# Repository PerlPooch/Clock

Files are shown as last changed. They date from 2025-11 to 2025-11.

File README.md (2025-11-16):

# Hardware

You can power Clock via the NodeMCU micro-USB port, but it is preferable to provide +5V power via the on-board connector or terminal J1. Driving the LEDs brighter than 50% when powered via the micro-USB connector may damage the NodeMCU.

A ring of 60 WS2812B LEDs are connected to J5 or J2 (but not both). Pin 1 is ground, Pin 2 is data, Pin 3 is +5. See [[RGB Clock Controller/Schematic.pdf][The Schematic]] for details. 

Dual connectors J3 are provided for an optional small OLED display. Select the header that matches the orientation of the display.

# Software 2.11

## Wifi Configuration

If there is no configuration present or Clock is powered-on with button (SW3) depressed, Clock enters WiFi configuration mode.

In this mode, Clock will create a WiFi access point with the SSID `Clock xx:xx:xx:xx:xx:xx`. Join this AP with the password `12345678` and you will be presented with menus through which you can select and join an Internet-connected AP.

Once configured, Clock will reboot.

## USB-Serial Access

Clock will provide a serial interface via USB at 115200/8/n/1.

## OpenWeather

If you have an OpenWeather key, Clock will obtain the weather by making requests to 

    GET http://api.openweathermap.org/data/2.5/weather

using the configured key. You must set `owAppKey`, `latitude`, and `longitude`.

## Start Up

Clock will test the display, connect to the configured WiFi AP, and retrieve the current date and time via NTP. 

## Configuration

You can reach Clock via HTTP at its address. If you don't know the address that was assigned, you can enter WiFi Configuration mode and view the assigned IP address. Alternatively, the assigned IP address is available via the Serial connection upon start up.

### Query Values and Status

Making a GET request to / will return a JSON payload of the current configuration. 

    http://<clockip>/

| Field | Meaning / Range |
| :--- | :--- |
| **"sleepRemaining"** | `<int>` – Remaining **sleep time** in seconds |
| **"timezone"** | `<int>` – **Timezone offset** from OpenWeather data |
| **"nextNTPUpdate"**  | `<int>` – Seconds until the next **NTP time update** |
| **"nextOWUpdate"** | `<int>` – Seconds until the next **OpenWeather update** |
| **"temperature"** | `<int>` – Current **temperature (°F)** |
| **"lastOWResponse"** | `<int>` – Last **HTTP response code** from OpenWeather |
| **"time"** | `<string>` – Current **time** |
| **"display"** | `<string>` – Display state (**Day**, **Night**, **Sleep**, or **Preparing**) |
| **"version"** | `<string>` – Clock **firmware version** |

### Set Values

Making a GET request with a query-string can configure the options. 

For example, to set the dim intensity and bright intensity for both daytime and nighttime modes:

    http://clockip/?dim=7&bright=20&dimNight=7&brightNight=20

| Option | Meaning / Range |
| :--- | :--- |
| **"dim"** | `0 .. 100` – Brightness of standard dots during **Day time** |
| **"bright"** | `0 .. 100` – Brightness of tick dots during **Day time** |
| **"dimNight"** | `0 .. 100` – Brightness of standard dots during **Night time** |
| **"brightNight"**  | `0 .. 100` – Brightness of tick dots during **Night time** |
| **"temp"** | `0 .. 100` – Brightness of temperature dot when **sleeping** |
| **"hue"** | `0 .. 100` – Universal **color shift** to apply |
| **"coldHue"** | `0 .. 100` – Color of temperature dot when **temperature < 60°** |
| **"warmHue"** | `0 .. 100` – Color of temperature dot when **temperature > 60°** |
| **"nightHour"** | `0 .. 23` – Hour to **start Night time** |
| **"dayHour"** | `0 .. 23` – Hour to **end Night time** |
| **"owAppKey"** | `<string>` – **OpenWeather API Key** |
| **"latitude"** | `<float>` – Location **Latitude** |
| **"longitude"** | `<float>` – Location **Longitude** |
| **"displaySleep"** | `<int>` – Sleep the display for this many **seconds** |
| **"reboot"** | `<>` – **Reboot** |

## OTA Firmware Update

    GET http://<clockip>/_ac/update

## WiFi Configuration Changes

    GET http://<clockip>/_ac/

# Building

Clock is based on the (now old) NodeMCU 12E ESP8266 board. 

## Libraries

The Arduino community is great, offering many useful libraries to build upon. This project requires:

* SPI
* Wire
* Adafruit GFX Library
* Adafruit SSD1306
* arduino-timer
* ArduinoJson
* ESP8266WiFi
* ESP8266WebServer
* AutoConnect
* LittleFS
* ESP8266HTTPClient
* NeoPixelBus by Makuna
* NTPClient

These Libraries, in turn, require:

* Adafruit BusIO
* DNSServer
* EEPROM
* PageBuilder
* SD
* SDFS
* ESP8266SdFat
* Ticker
* ESP8266httpUpdate

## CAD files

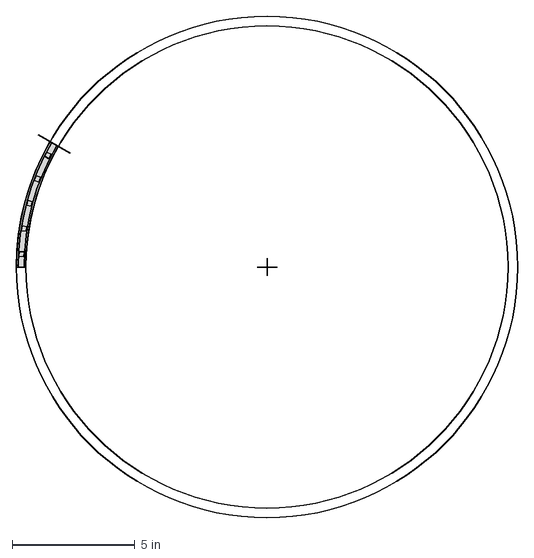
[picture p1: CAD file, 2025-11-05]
RGB Clock LED Ring/Design and Guides/Outline.dxf
20.4 x 20.4 in

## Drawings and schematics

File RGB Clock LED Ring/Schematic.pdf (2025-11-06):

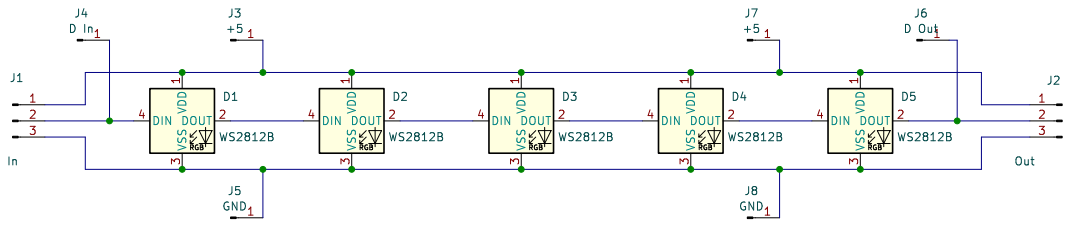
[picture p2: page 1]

Id: 1/1 Title: File: RGB Clock.kicad_sch Sheet: /

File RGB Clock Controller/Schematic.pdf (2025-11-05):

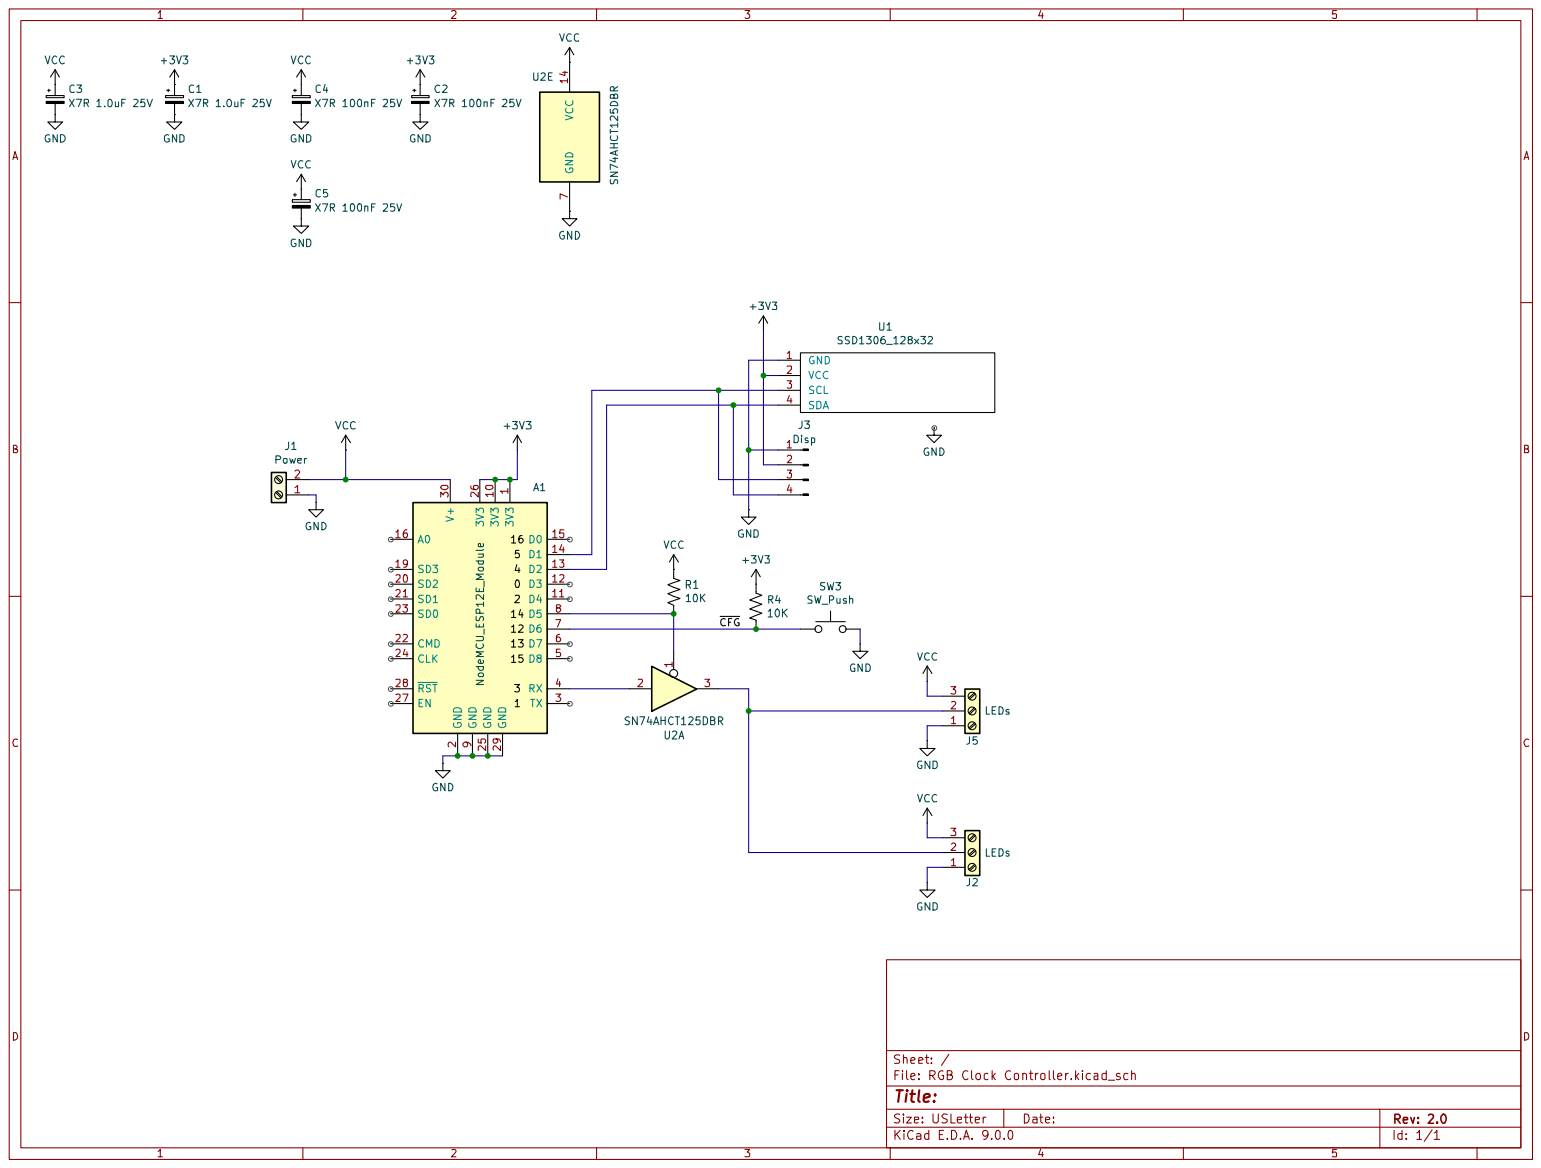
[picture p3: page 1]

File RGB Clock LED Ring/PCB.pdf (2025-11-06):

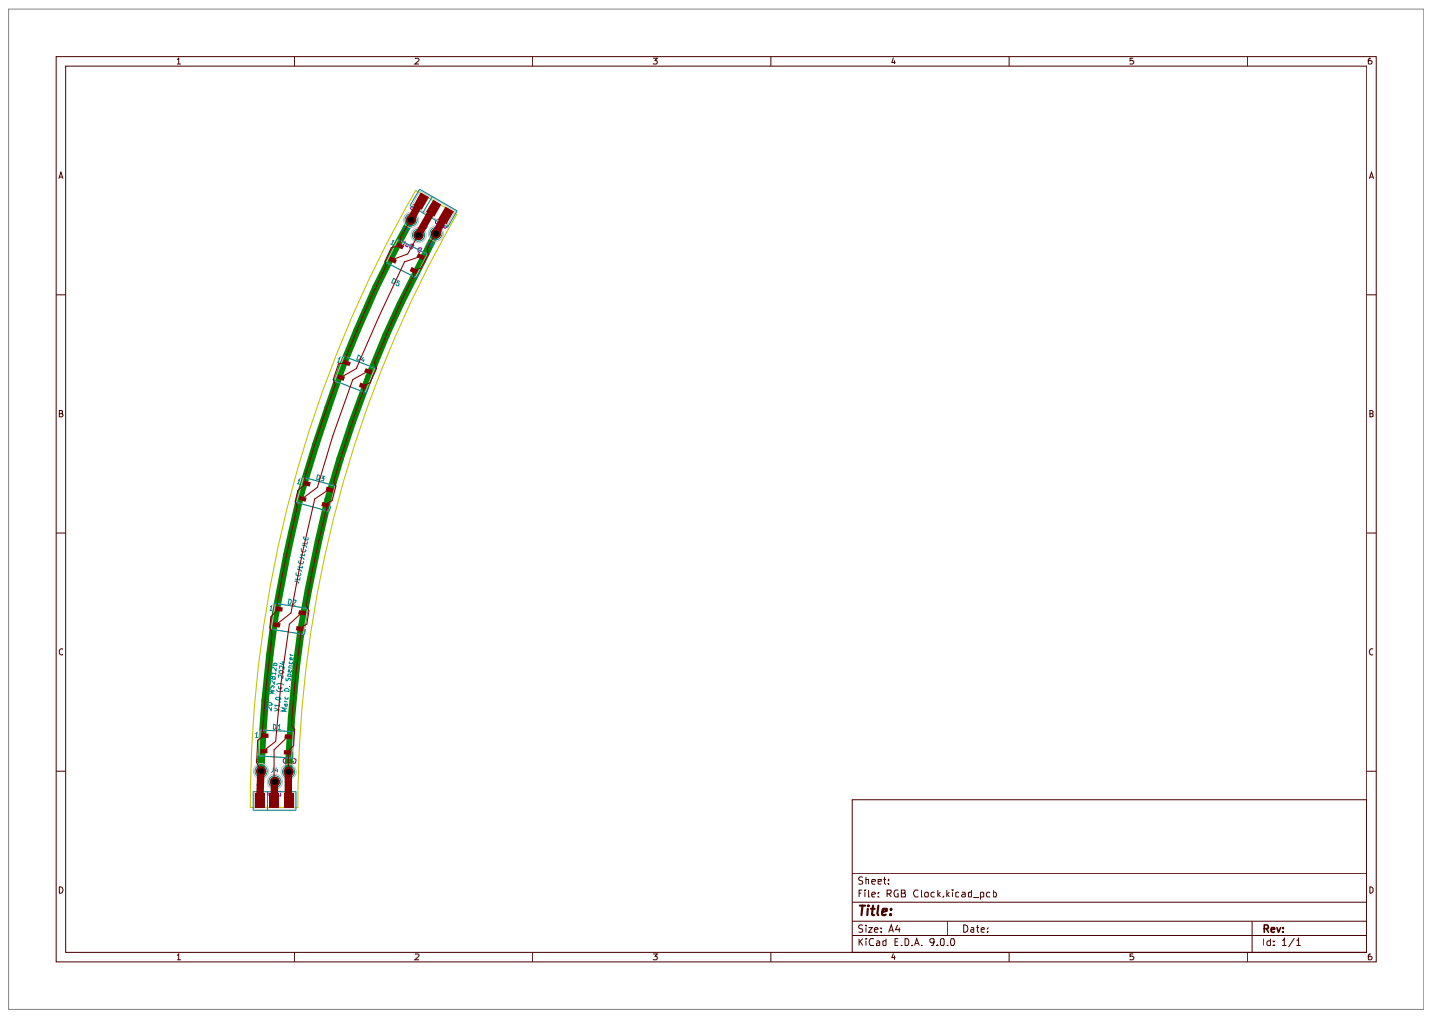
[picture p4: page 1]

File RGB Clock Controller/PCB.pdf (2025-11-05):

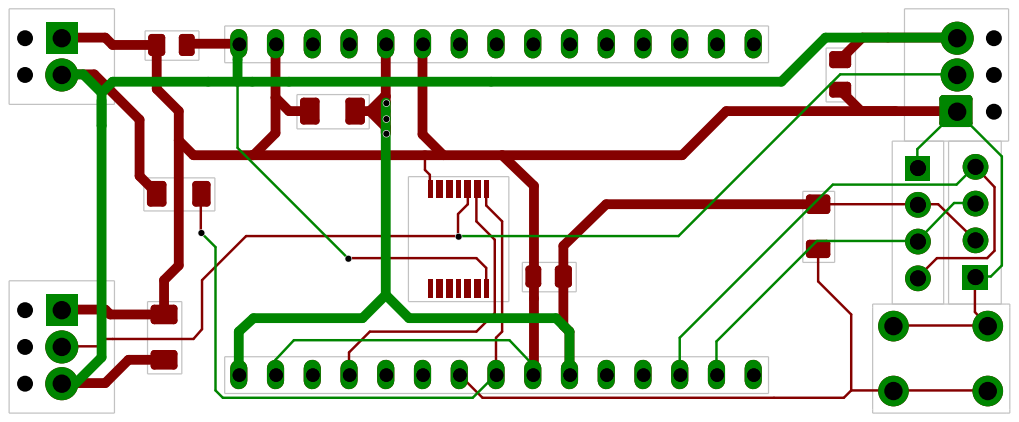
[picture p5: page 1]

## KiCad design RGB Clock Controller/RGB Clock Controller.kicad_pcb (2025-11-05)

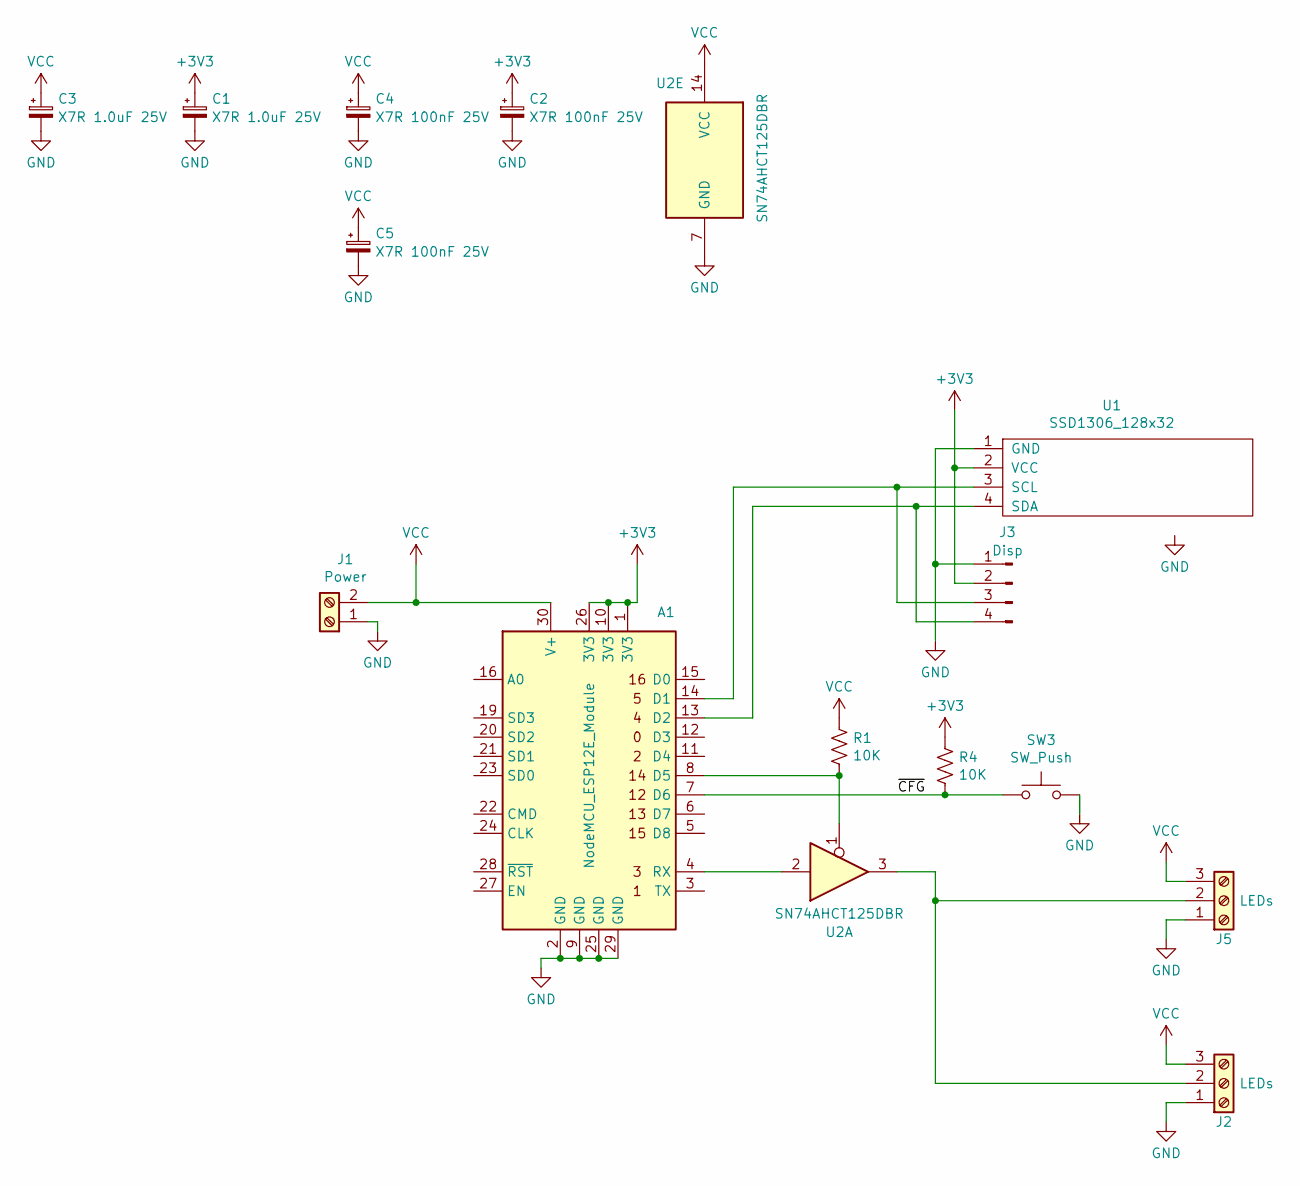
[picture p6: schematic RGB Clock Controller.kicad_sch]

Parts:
A1: NodeMCU_ESP12E_Module; NodeMCU
C1, C3: X7R 1.0uF 25V; C_1206_3216Metric_Pad1.33x1.80mm_HandSolder
C2, C4, C5: X7R 100nF 25V; C_0805_2012Metric_Pad1.18x1.45mm_HandSolder
J1: Power; TerminalBlock_Phoenix_MPT-0,5-2-2.54_1x02_P2.54mm_Horizontal
J2, J5: LEDs; TerminalBlock_Phoenix_MPT-0,5-3-2.54_1x03_P2.54mm_Horizontal
J3: Disp; PinHeader_1x04_P2.54mm_Vertical
R1, R4: 10K; R_1206_3216Metric_Pad1.30x1.75mm_HandSolder
SW3: SW_Push; SW_PUSH_6mm_H4.3mm
U1: SSD1306_128x32; PinHeader_1x04_P2.54mm_Vertical
U2: SN74AHCT125DBR; SSOP-14_5.3x6.2mm_P0.65mm

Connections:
+3V3: A1.1 (3V3), A1.10 (3V3), A1.26 (3V3), C1.1, C2.1, J3.2, R4.1, U1.2 (VCC)
/~CFG: A1.7 (D6), R4.2, SW3.1
GND: A1.2 (GND), A1.9 (GND), A1.25 (GND), A1.29 (GND), C1.2, C2.2, C3.2, C4.2, C5.2, J1.1, J2.1, J3.1, J5.1, SW3.2, U1.1 (GND), U2.7 (GND)
unnamed: A1.14 (D1), J3.3, U1.3 (SCL)
unnamed: A1.13 (D2), J3.4, U1.4 (SDA)
unnamed: A1.8 (D5), R1.2, U2.1
unnamed: A1.4 (RX), U2.2
unnamed: J2.2, J5.2, U2.3
VCC: A1.30 (V+), C3.1, C4.1, C5.1, J1.2, J2.3, J5.3, R1.1, U2.14 (VCC)

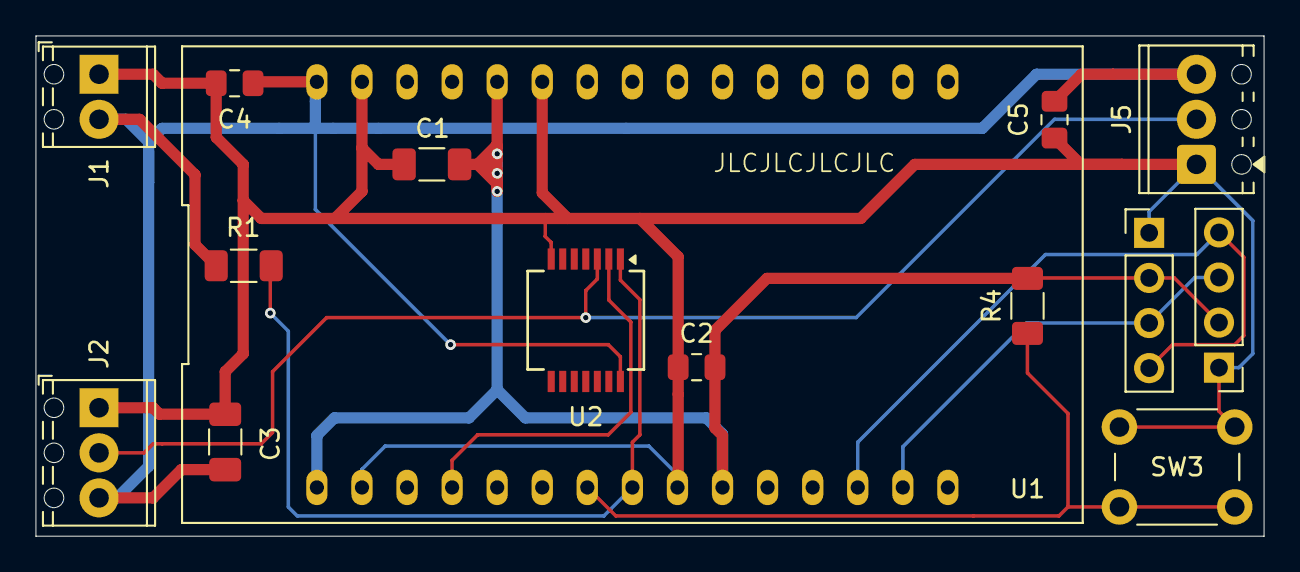
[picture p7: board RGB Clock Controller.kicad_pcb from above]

Board: 2 copper layers, 69.2 x 28.2 mm, 15 parts (0 on the bottom side), 9 nets.

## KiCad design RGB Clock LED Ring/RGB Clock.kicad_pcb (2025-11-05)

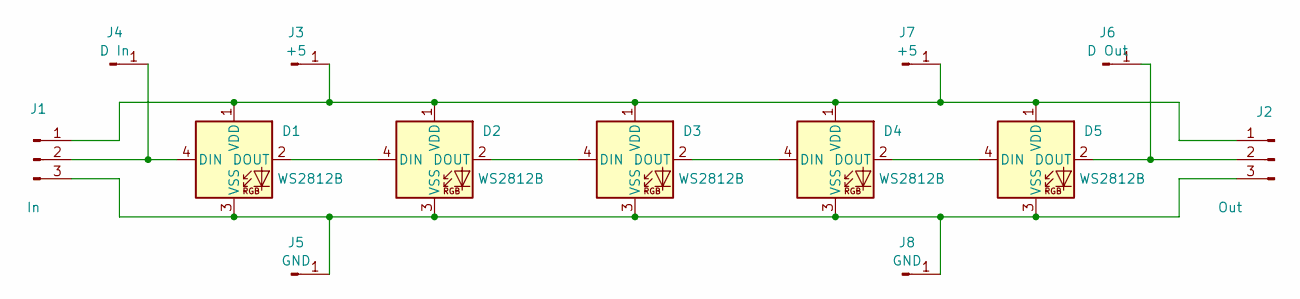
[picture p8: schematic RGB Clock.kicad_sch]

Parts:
D1, D2, D3, D4, D5: WS2812B; LED_WS2812B_PLCC4_5.0x5.0mm_P3.2mm
J1: In; Connector 2.0mm 5.0mm on 2.5mm
J2: Out; Connector 2.0mm 5.0mm on 2.5mm
J3, J7: +5; Pin_D1.0mm_L10.0mm
J4: D In; Pin_D1.0mm_L10.0mm
J5, J8: GND; Pin_D1.0mm_L10.0mm
J6: D Out; Pin_D1.0mm_L10.0mm

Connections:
unnamed: D1.4 (DIN), J1.2, J4.1
unnamed: D1.2 (DOUT), D2.4 (DIN)
unnamed: D1.1 (VDD), D2.1 (VDD), D3.1 (VDD), D4.1 (VDD), D5.1 (VDD), J1.1, J2.1, J3.1, J7.1
unnamed: D1.3 (VSS), D2.3 (VSS), D3.3 (VSS), D4.3 (VSS), D5.3 (VSS), J1.3, J2.3, J5.1, J8.1
unnamed: D2.2 (DOUT), D3.4 (DIN)
unnamed: D3.2 (DOUT), D4.4 (DIN)
unnamed: D4.2 (DOUT), D5.4 (DIN)
unnamed: D5.2 (DOUT), J2.2, J6.1

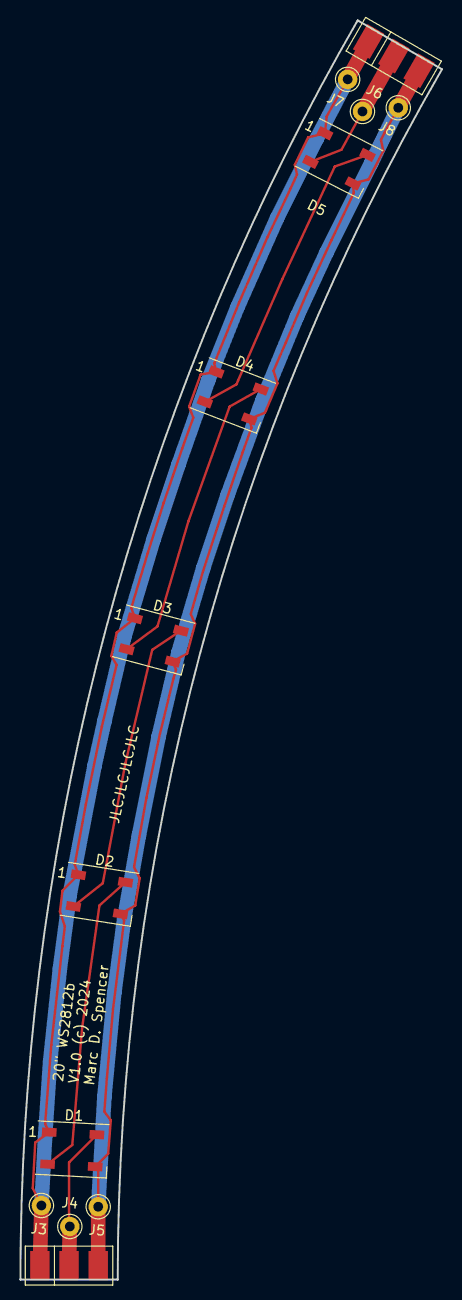
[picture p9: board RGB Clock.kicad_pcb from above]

Board: 2 copper layers, 43.4 x 129.5 mm, 13 parts (0 on the bottom side), 8 nets.

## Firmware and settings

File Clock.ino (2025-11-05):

// ---- Configuration -------------------------------------------------------------------
//
#define USE_LEDSTRIP

//
// --------------------------------------------------------------------------------------

#include "config.h"
#include "MDS_Display.h"
#include "MDS_AppConfig.h"
#include "MDS_AutoWiFi.h"

#include <ESP8266WiFi.h>
#include <ESP8266WebServer.h>
#ifdef USE_LEDSTRIP
#include <NeoPixelBusLg.h>
#include <NeoPixelAnimator.h>
#endif
#include <Arduino.h>
#include <FS.h>
#include <NTPClient.h>

#include <ESP8266HTTPClient.h>

// --------------------------------------------------------------------------------------

#define VERSION				"2.11"
#define PROJECT_VERSION		"Clock " VERSION


// curl -s 'http://192.168.0.29?dim=10&bright=50&dimNight=8&brightNight=20'

// curl -s 'http://192.168.0.29?dim=10&bright=50&dimNight=0&brightNight=0&temp=10&hue=0&nightHour=22&dayHour=9'
// curl -s 'http://192.168.0.29?latitude=42.49988&longitude=-71.27531&coldHue=45&warmHue=11'
// curl -s 'http://192.168.0.29?owAppKey=TOKEN'

char				systemID[32];		// System ID. Based on the WiFi MAC

bool				isConfigured = false;

MDS_Display			display;
MDS_AppConfig		appConfig;
MDS_AutoWiFi		autoWiFi;

#ifdef USE_LEDSTRIP
// Pin is _fixed to be GPIO3 (RX pin)
// NeoPixelBusLg<NeoGrbFeature, NeoWs2812xMethod, NeoGammaCieLabEquationMethod> strip(NUM_LEDSTRIP);
NeoPixelBusLg<NeoGrbFeature, NeoWs2812xMethod, NeoGammaNullMethod> strip(NUM_LEDSTRIP);
//NeoGamma<NeoGammaTableMethod> colorGamma;
NeoGamma<NeoGammaEquationMethod> colorGamma;

WiFiUDP ntpUDP;
NTPClient timeClient(ntpUDP, (24-4) * 3600);	// TODO: Set Timezone from OpenWeather

#define GAMMA 1.8f
// #define RGB(r, g, b) (RgbColor((pow(r / 255.0f, GAMMA) * 255) + 0.5f, (pow(g / 255.0f, GAMMA) * 255) + 0.5f, (pow(b / 255.0f, GAMMA) * 255) + 0.5f))
#define RGB(r, g, b) (RgbColor(gammaTable[r], gammaTable[g], gammaTable[b]))

#endif

uint8_t gammaTable[256];  // Lookup table for gamma correction

unsigned long epoch;
float dimPct;
float brightPct;
float tempPct;
int timezone;
int temperature;
int httpResponseCode;
unsigned long lastEpoch;
unsigned long nextNTPUpdate;
unsigned long nextTemperatureUpdate;
unsigned long nextRebootUpdate;
unsigned long nextDisplayUpdate;
uint32_t displaySleepSeconds;

#define DISP_ST_NIGHT				1
#define DISP_ST_WAKING				2
#define DISP_ST_DAY 				3
#define DISP_ST_NODDING				4
#define DISP_ST_SLEEPING			5
#define DISP_ST_SLEEP				6

uint8_t displayState = DISP_ST_DAY;
uint8_t targetDisplayState = DISP_ST_DAY;
uint8_t displayStep;
uint8_t openWeatherTries = 0;

// ---- AppConfig

struct AppConfig {
	bool		isConfigured;
	char		MQTTName[32];
	char		MQTTBroker[64];
	uint16_t	MQTTPort;
	uint8_t		dimLEDPercentage;
	uint8_t		brightLEDPercentage;
	uint8_t		dimNightLEDPercentage;
	uint8_t		brightNightLEDPercentage;
	uint8_t		temperatureLEDPercentage;
	uint8_t		LEDHuePercentage;
	uint8_t		nightHour;
	uint8_t		dayHour;
	char		owAppKey[33];
	char		latitude[11];
	char		longitude[11];
	uint8_t		LEDColdHuePercentage;
	uint8_t		LEDWarmHuePercentage;
};
AppConfig appConfigData;

void setConfigurationCB(const JsonDocument &doc) {
// Serial.println("setConfigurationCB");
	appConfigData.isConfigured = doc[jc_IS_CONFIGURED];

	strlcpy(appConfigData.MQTTName, doc[jc_MQTTNAME], sizeof(appConfigData.MQTTName));
	strlcpy(appConfigData.MQTTBroker, doc[jc_MQTTBROKER], sizeof(appConfigData.MQTTBroker));
	appConfigData.MQTTPort = doc[jc_MQTTPORT];
	appConfigData.dimLEDPercentage = doc[jc_DIMLEDPERCENTAGE];
	appConfigData.brightLEDPercentage = doc[jc_BRIGHTLEDPERCENTAGE];
	appConfigData.dimNightLEDPercentage = doc[jc_DIMNIGHTLEDPERCENTAGE];
	appConfigData.brightNightLEDPercentage = doc[jc_BRIGHTNIGHTLEDPERCENTAGE];
	appConfigData.temperatureLEDPercentage = doc[jc_TEMPERATUREPERCENTAGE];
	appConfigData.LEDHuePercentage = doc[jc_LEDHUEPERCENTAGE];
	appConfigData.nightHour = doc[jc_NIGHTHOUR];
	appConfigData.dayHour = doc[jc_DAYHOUR];
	strlcpy(appConfigData.owAppKey, doc[jc_OWKEY], sizeof(appConfigData.owAppKey));
	strlcpy(appConfigData.latitude, doc[jc_OWLAT], sizeof(appConfigData.latitude));
	strlcpy(appConfigData.longitude, doc[jc_OWLON], sizeof(appConfigData.longitude));
	appConfigData.LEDColdHuePercentage = doc[jc_LEDCOLDHUEPERCENTAGE];
	appConfigData.LEDWarmHuePercentage = doc[jc_LEDWARMHUEPERCENTAGE];
	
	if(!appConfigData.isConfigured) {
		appConfigData.dimLEDPercentage = 15;
		appConfigData.brightLEDPercentage = 40;
		appConfigData.dimNightLEDPercentage = 5;
		appConfigData.brightNightLEDPercentage = 10;
		appConfigData.temperatureLEDPercentage = 10;
		appConfigData.LEDHuePercentage = 0;
		appConfigData.nightHour = 21;
		appConfigData.dayHour = 06;
		
		strlcpy(appConfigData.owAppKey, "", sizeof(appConfigData.owAppKey));
		strlcpy(appConfigData.latitude, "", sizeof(appConfigData.latitude));
		strlcpy(appConfigData.longitude, "", sizeof(appConfigData.longitude));

		appConfigData.LEDColdHuePercentage = 45;
		appConfigData.LEDWarmHuePercentage = 11;
		
		appConfigData.isConfigured = true;
	}
}

void getConfigurationCB(JsonDocument &doc) {
	doc[jc_IS_CONFIGURED]				= appConfigData.isConfigured;

	doc[jc_MQTTNAME]					= appConfigData.MQTTName;
	doc[jc_MQTTBROKER]					= appConfigData.MQTTBroker;
	doc[jc_MQTTPORT] 					= appConfigData.MQTTPort;
	doc[jc_DIMLEDPERCENTAGE]			= appConfigData.dimLEDPercentage;
	doc[jc_BRIGHTLEDPERCENTAGE]			= appConfigData.brightLEDPercentage;
	doc[jc_DIMNIGHTLEDPERCENTAGE]		= appConfigData.dimNightLEDPercentage;
	doc[jc_BRIGHTNIGHTLEDPERCENTAGE]	= appConfigData.brightNightLEDPercentage;
	doc[jc_TEMPERATUREPERCENTAGE]		= appConfigData.temperatureLEDPercentage;
	doc[jc_LEDHUEPERCENTAGE]			= appConfigData.LEDHuePercentage;
	doc[jc_NIGHTHOUR]					= appConfigData.nightHour;
	doc[jc_DAYHOUR]						= appConfigData.dayHour;
	doc[jc_OWKEY]						= appConfigData.owAppKey;
	doc[jc_OWLAT]						= appConfigData.latitude;
	doc[jc_OWLON]						= appConfigData.longitude;
	doc[jc_LEDCOLDHUEPERCENTAGE]		= appConfigData.LEDColdHuePercentage;
	doc[jc_LEDWARMHUEPERCENTAGE]		= appConfigData.LEDWarmHuePercentage;
}

// ---- autoWiFi

void savePortalConfigurationCB(String name, String broker, String port) {
	Serial.println(F("savePortalConfigurationCB()"));

	strlcpy(appConfigData.MQTTName, name.c_str(), name.length() + 1);
	strlcpy(appConfigData.MQTTBroker, broker.c_str(), broker.length() + 1);
	appConfigData.MQTTPort = (uint16_t)port.toInt();

	appConfig.save();
	appConfig.print();
}

// ---- 

void generateGammaTable() {
    for (int i = 0; i <= 255; i++) {
        float normalized = i / 255.0;
        gammaTable[i] = round(pow(i / 255.0, GAMMA) * 255.0); 
//		Serial.println(String(i) + " " + String(gammaTable[i]));
    }
}

void rootPage() {
	char	data[CONFIG_DOC_SIZE];
	
	if(autoWiFi.getWebServer()->args() > 0) {
		if(autoWiFi.getWebServer()->hasArg(F(jc_BRIGHTLEDPERCENTAGE))) {
			uint8_t val = autoWiFi.getWebServer()->arg(F(jc_BRIGHTLEDPERCENTAGE)).toInt();

			if(val > 100) val = 100;
			if(val < 0) val = 0;
			Serial.println("Got bright: " + String(val));

			appConfigData.brightLEDPercentage = val;

			appConfig.save();
			appConfig.print();
		}
		if(autoWiFi.getWebServer()->hasArg(F(jc_DIMLEDPERCENTAGE))) {
			uint8_t val = autoWiFi.getWebServer()->arg(F(jc_DIMLEDPERCENTAGE)).toInt();
			if(val > 100) val = 100;
			if(val < 0) val = 0;
			Serial.println("Got dim: " + String(val));

			appConfigData.dimLEDPercentage = val;

			appConfig.save();
			appConfig.print();
		}
		if(autoWiFi.getWebServer()->hasArg(F(jc_BRIGHTNIGHTLEDPERCENTAGE))) {
			uint8_t val = autoWiFi.getWebServer()->arg(F(jc_BRIGHTNIGHTLEDPERCENTAGE)).toInt();
			if(val > 100) val = 100;
			if(val < 0) val = 0;
			Serial.println("Got bright night: " + String(val));

			appConfigData.brightNightLEDPercentage = val;

			appConfig.save();
			appConfig.print();
		}
		if(autoWiFi.getWebServer()->hasArg(F(jc_DIMNIGHTLEDPERCENTAGE))) {
			uint8_t val = autoWiFi.getWebServer()->arg(F(jc_DIMNIGHTLEDPERCENTAGE)).toInt();
			if(val > 100) val = 100;
			if(val < 0) val = 0;
			Serial.println("Got dim night: " + String(val));

			appConfigData.dimNightLEDPercentage = val;

			appConfig.save();
			appConfig.print();
		}
		if(autoWiFi.getWebServer()->hasArg(F(jc_TEMPERATUREPERCENTAGE))) {
			uint8_t val = autoWiFi.getWebServer()->arg(F(jc_TEMPERATUREPERCENTAGE)).toInt();
			if(val > 100) val = 100;
			if(val < 0) val = 0;
			Serial.println("Got temp brightness: " + String(val));

			appConfigData.temperatureLEDPercentage = val;

			appConfig.save();
			appConfig.print();
		}
		if(autoWiFi.getWebServer()->hasArg(F(jc_LEDHUEPERCENTAGE))) {
			uint8_t val = autoWiFi.getWebServer()->arg(F(jc_LEDHUEPERCENTAGE)).toInt();

			if(val > 100) val = 100;
			if(val < 0) val = 0;
			Serial.println("Got hue: " + String(val));

			appConfigData.LEDHuePercentage = val;

			appConfig.save();
			appConfig.print();
		}
		if(autoWiFi.getWebServer()->hasArg(F(jc_NIGHTHOUR))) {
			uint8_t val = autoWiFi.getWebServer()->arg(F(jc_NIGHTHOUR)).toInt();
			if(val > 23) val = 23;
			Serial.println("Got night hour: " + String(val));

			appConfigData.nightHour = val;

			appConfig.save();
			appConfig.print();
		}
		if(autoWiFi.getWebServer()->hasArg(F(jc_DAYHOUR))) {
			uint8_t val = autoWiFi.getWebServer()->arg(F(jc_DAYHOUR)).toInt();
			if(val > 23) val = 23;
			Serial.println("Got day hour: " + String(val));

			appConfigData.dayHour = val;

			appConfig.save();
			appConfig.print();
		}
		if(autoWiFi.getWebServer()->hasArg(F(jc_MQTTNAME))) {
			String name = autoWiFi.getWebServer()->arg(F(jc_MQTTNAME));
			Serial.println("Got device Name: " + name);

			strlcpy(appConfigData.MQTTName, name.c_str(), sizeof(appConfigData.MQTTName));

			autoWiFi.getWebServer()->send(200, "application/json", name);

			appConfig.save();
			appConfig.print();
		}

		if(autoWiFi.getWebServer()->hasArg(F(jc_OWKEY))) {
			String name = autoWiFi.getWebServer()->arg(F(jc_OWKEY));
			Serial.println("Got OpenWeather Key: " + name);

			strlcpy(appConfigData.owAppKey, name.c_str(), sizeof(appConfigData.owAppKey));

			nextTemperatureUpdate = 0;
			appConfig.save();
			appConfig.print();
		}
		if(autoWiFi.getWebServer()->hasArg(F(jc_OWLAT))) {
			String name = autoWiFi.getWebServer()->arg(F(jc_OWLAT));
			Serial.println("Got latitude: " + name);

			strlcpy(appConfigData.latitude, name.c_str(), sizeof(appConfigData.latitude));

			nextTemperatureUpdate = 0;
			appConfig.save();
			appConfig.print();
		}
		if(autoWiFi.getWebServer()->hasArg(F(jc_OWLON))) {
			String name = autoWiFi.getWebServer()->arg(F(jc_OWLON));
			Serial.println("Got longitude: " + name);

			strlcpy(appConfigData.longitude, name.c_str(), sizeof(appConfigData.longitude));

			nextTemperatureUpdate = 0;
			appConfig.save();
			appConfig.print();
		}
		if(autoWiFi.getWebServer()->hasArg(F(jc_LEDCOLDHUEPERCENTAGE))) {
			uint8_t val = autoWiFi.getWebServer()->arg(F(jc_LEDCOLDHUEPERCENTAGE)).toInt();

			if(val > 100) val = 100;
			if(val < 0) val = 0;
			Serial.println("Got cold hue: " + String(val));

			appConfigData.LEDColdHuePercentage = val;

			appConfig.save();
			appConfig.print();
		}
		if(autoWiFi.getWebServer()->hasArg(F(jc_LEDWARMHUEPERCENTAGE))) {
			uint8_t val = autoWiFi.getWebServer()->arg(F(jc_LEDWARMHUEPERCENTAGE)).toInt();

			if(val > 100) val = 100;
			if(val < 0) val = 0;
			Serial.println("Got warm hue: " + String(val));

			appConfigData.LEDWarmHuePercentage = val;

			appConfig.save();
			appConfig.print();
		}
		if(autoWiFi.getWebServer()->hasArg(F(jc_DSLEEP))) {
			uint32_t val = autoWiFi.getWebServer()->arg(F(jc_DSLEEP)).toInt();

			if(val > 86400) val = 86400;
			if(val < 0) val = 0;
			Serial.println("Got display sleep: " + String(val));

			displaySleepSeconds = val;
		}
		if(autoWiFi.getWebServer()->hasArg(F(jc_REBOOT))) {
			displaySleepSeconds = 60; // Must be longer than the reboot ...
			nextRebootUpdate = millis()/1000 + 10;
		}
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
void loop() {
	char buffer[30];

	if(displayState == DISP_ST_NIGHT || displayState == DISP_ST_DAY || displayState == DISP_ST_SLEEP ) {
		display.tick();
		autoWiFi.tick();
	}
	
	unsigned long now = millis()/1000;
	
//  	Serial.println("now: " + String(now));
//  	Serial.println("nextNTPUpdate: " + String(nextNTPUpdate));

	if(nextRebootUpdate > 0 && now >= nextRebootUpdate) {
		Serial.println("Restarting ...");
		delay(3);
	    ESP.restart();
	}

	if(now >= nextNTPUpdate) {
		Serial.println("Time Update: " + String(now) + "/" + String(nextNTPUpdate) + " ");
		display.D("Updating Time...");
					
		if(timeClient.forceUpdate()) {
			Serial.println(F("Happy update."));
			nextNTPUpdate = now + 3600;
		} else {
			Serial.println(F("Sad update."));
		}
	}
	
	if(now >= nextTemperatureUpdate && openWeatherTries < OPENWEATHER_MAX_TRIES) {
		if(strlen(appConfigData.owAppKey) != 0) {
			Serial.println("Weather Update: " + String(now) + "/" + String(nextTemperatureUpdate) + " Attempt: " + openWeatherTries );
			display.D("Updating Weather...");
	
			String owURL = "http://api.openweathermap.org/data/2.5/weather?"
						   "lat=" + String(appConfigData.latitude) +
						   "&lon=" + String(appConfigData.longitude) +
						   "&exclude=hourly,minutely&units=imperial" +
						   "&appid=" + appConfigData.owAppKey;
					
			Serial.println("GET " + owURL);
	
			WiFiClient client;
			HTTPClient http;
	
			http.begin(client, owURL.c_str());
			httpResponseCode = http.GET();	// this is global so we can track the last call
	
			if(httpResponseCode > 0) {
				Serial.print("HTTP Response code: ");
				Serial.println(httpResponseCode);
				String payload = http.getString();
				Serial.println(payload);
			
				StaticJsonDocument<1000> doc;
				DeserializationError error = deserializeJson(doc, payload);
	
				if(error) {
					Serial.print(F("AppConfig: Unable to read configuration: "));
					Serial.println(error.c_str());
				} else if(httpResponseCode == 200) {
					timezone = doc["timezone"];
					Serial.print("timezone: ");
					Serial.println(timezone / 3600);

					JsonObject mainObj = doc["main"];
	
					if (mainObj.containsKey("temp")) {
						temperature = int(mainObj["temp"].as<float>() + 0.5f);
						Serial.print("Temperature: ");
						Serial.println(temperature);
						
						nextTemperatureUpdate = now + OPENWEATHER_UPDATE;
						
 						timeClient.setTimeOffset(timezone);
						
						openWeatherTries = 0;
					} else {
						Serial.println("Key 'temp' not found");
						nextTemperatureUpdate = now + OPENWEATHER_UPDATE;
						openWeatherTries ++;
					}
				} else {
					nextTemperatureUpdate = now + OPENWEATHER_UPDATE;
					openWeatherTries ++;
				}
			} else {
				Serial.print("Error code: ");
				Serial.println(httpResponseCode);
				nextTemperatureUpdate = now + OPENWEATHER_UPDATE;
				openWeatherTries ++;
			}
	
			http.end();
		} else {
			Serial.println("Weather Update skipped. No key.");
			nextTemperatureUpdate = now + OPENWEATHER_UPDATE;
		}
	}
	
// #define DEBUG_NTPClient 1

	RgbColor p;
 	if(timeClient.isTimeSet()) {

		if((displayStep > 0) && (millis() >= nextDisplayUpdate)) {
			if(displayState == DISP_ST_NODDING) {
				float pos = (float)displayStep / DISP_FADE_STEPS;
				
				dimPct = (float) (appConfigData.dimNightLEDPercentage + 
					(appConfigData.dimLEDPercentage - appConfigData.dimNightLEDPercentage) * pos)/100; 
				brightPct = (float) (appConfigData.brightNightLEDPercentage + 
					(appConfigData.brightLEDPercentage - appConfigData.brightNightLEDPercentage) * pos)/100; 

			}
			if(displayState == DISP_ST_WAKING) {
				float pos = 1.0 - (float)displayStep / DISP_FADE_STEPS;
				
				dimPct = (float) (appConfigData.dimNightLEDPercentage + 
					(appConfigData.dimLEDPercentage - appConfigData.dimNightLEDPercentage) * pos)/100; 
				brightPct = (float) (appConfigData.brightNightLEDPercentage + 
					(appConfigData.brightLEDPercentage - appConfigData.brightNightLEDPercentage) * pos)/100; 
			}
			if(displayState == DISP_ST_SLEEPING) {
				float pos = (float)displayStep / DISP_FADE_STEPS;
				
				dimPct = (float) (0 + 
					(appConfigData.dimLEDPercentage - 0) * pos)/100; 
				brightPct = (float) (0 + 
					(appConfigData.brightLEDPercentage - 0) * pos)/100;
			}

			displayStep --;

			if(displayState == DISP_ST_NODDING && displayStep == 0)		displayState = DISP_ST_NIGHT;
			if(displayState == DISP_ST_WAKING && displayStep == 0)		displayState = DISP_ST_DAY;
			if(displayState == DISP_ST_SLEEPING && displayStep == 0)	displayState = DISP_ST_SLEEP;

			nextDisplayUpdate = millis() + DISP_FADE_TIME;
		} else if(displayState == DISP_ST_DAY) {
			dimPct = (float) appConfigData.dimLEDPercentage/100;
			brightPct = (float) appConfigData.brightLEDPercentage/100;
		} else if(displayState == DISP_ST_NIGHT) {
			dimPct = (float) appConfigData.dimNightLEDPercentage/100;
			brightPct = (float) appConfigData.brightNightLEDPercentage/100;
		}

		tempPct = (float) appConfigData.temperatureLEDPercentage/100;

		epoch = timeClient.getEpochTime();

		if(
			((displayState == DISP_ST_NODDING || displayState == DISP_ST_WAKING || displayState == DISP_ST_SLEEPING) && millis() >= nextDisplayUpdate)
			|| lastEpoch < epoch) {

			int h = timeClient.getHours();
			int m = timeClient.getMinutes();
			int	s = timeClient.getSeconds();

			// If it's night and we think it should be day
			if((displayState == DISP_ST_NIGHT) && (h >= appConfigData.dayHour) && (h < appConfigData.nightHour)) {
// 			if((displayState == DISP_ST_NIGHT) && ! digitalRead(PIN_RESET_WIFI)) {
				displayState = DISP_ST_WAKING;
				displayStep = DISP_FADE_STEPS;
				nextDisplayUpdate = millis() + DISP_FADE_TIME;
			}

			// If it's day and we think it should be night
			if((displayState == DISP_ST_DAY) && !((h >= appConfigData.dayHour) && (h < appConfigData.nightHour))) {
// 			if((displayState == DISP_ST_DAY) && digitalRead(PIN_RESET_WIFI)) {
				displayState = DISP_ST_NODDING;
				displayStep = DISP_FADE_STEPS;
				nextDisplayUpdate = millis() + DISP_FADE_TIME;
			}

			if((displayState == DISP_ST_DAY || displayState == DISP_ST_NIGHT) && (displaySleepSeconds)) {
				displayState = DISP_ST_SLEEPING;
				displayStep = DISP_FADE_STEPS;
				nextDisplayUpdate = millis() + DISP_FADE_TIME;
			}
			
			if(displayState == DISP_ST_DAY || displayState == DISP_ST_NIGHT || displayState == DISP_ST_SLEEP) {
				snprintf(buffer, sizeof(buffer), "%02u:%02u:%02u", h, m, s);

				Serial.print(String(buffer) + " " + String(timezone / 3600) + " " + String(nextNTPUpdate - now) + 
					" T: " + String(temperature) + " " + String(nextTemperatureUpdate - now) +
					(displayState == DISP_ST_SLEEP ? " Sleep" : (displayState == DISP_ST_DAY ? " Day":" Night") ));
				Serial.println(" [" + String(dimPct) + ", " + String(brightPct) + "]");

				if(! digitalRead(PIN_RESET_WIFI)) {
					display._clear();
	
					display.at(String(buffer) + " " + String(timezone / 3600) + " " + String(nextNTPUpdate - now) +
						(displayState == DISP_ST_SLEEP ? " Sleep" : (displayState == DISP_ST_DAY ? " Day":" Night") ), 0);
// 					display.at(WiFi.localIP().toString(), 12);
					display.at("T: " + String(temperature) + " " + String(nextTemperatureUpdate - now) + 
						" I: " + String((uint8_t)(dimPct*100)) + "% " + String((uint8_t)(brightPct*100)) + "%", 24);
					display.at(String(now) + " " + String(nextTemperatureUpdate), 12);
				} else {
					display.clearMessage();
				}
			} 

			if(displayState == DISP_ST_SLEEP) {
				Serial.println(" Sleeping: " + String(displaySleepSeconds));
				
				if(displaySleepSeconds == 0) {
					displayState = DISP_ST_WAKING;
					displayStep = DISP_FADE_STEPS;
					nextDisplayUpdate = millis() + DISP_FADE_TIME;
				}
			}
			
			bool isP = h > 12;
			h = h % 12;
			h = h * 5;
		
			for(int i = 0; i < 60; i++)
				strip.SetPixelColor(i, RgbColor(0,0,0));

			for(int i = 0; i < s+1; i++)
				strip.SetPixelColor(i, RgbColor(0, 0, 255));

			for(int i = 0; i < m+1; i++) {
				p = strip.GetPixelColor(i);
				strip.SetPixelColor(i, RgbColor(p.R, 255, p.B));
			}

			for(int i = 0; i < h+1; i++) {
				p = strip.GetPixelColor(i);
				strip.SetPixelColor(i, RgbColor(255, p.G, p.B));
			}

			for(int i = 0; i < 60; i++) {
				if(appConfigData.LEDHuePercentage != 0) {
					p = strip.GetPixelColor(i);

					HsbColor C = HsbColor(p);

					C.H += (float)appConfigData.LEDHuePercentage/100;
					if(C.H > 1.0) C.H -= 1.0;

					strip.SetPixelColor(i, C);
				}
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

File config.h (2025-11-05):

#define WIFI_CONFIG_NAME	"CLOCK"

#define PIN_RESET_WIFI 		12
#define PIN_LED 			16
#define PIN_LED_1			2		// NodeMCU Secondary LED (shares pin with relay!)
#define	PIN_ENABLESTRIP		14

#ifdef USE_LEDSTRIP
#define PIN_LEDSTRIP		3		// Pin is _fixed to be GPIO3 (RX pin)
#define NUM_LEDSTRIP		60
#endif

#define	DISP_FADE_TIME				2
#define DISP_FADE_STEPS				255
#define OPENWEATHER_MAX_TRIES		2
#define OPENWEATHER_UPDATE			600
#define OPENWEATHER_RETRY_UPDATE	60

// ---- AppConfig

#define jc_IS_CONFIGURED				"isConfigured"
#define jc_MQTTNAME						"MQTTName"
#define jc_MQTTBROKER					"MQTTBroker"
#define jc_MQTTPORT						"MQTTPort"
#define jc_DIMLEDPERCENTAGE				"dim"				// 0 .. 100. Brightness of standard dots when in Day time
#define jc_BRIGHTLEDPERCENTAGE			"bright"			// 0 .. 100. Brightness of Tick dots when in Day time
#define jc_DIMNIGHTLEDPERCENTAGE		"dimNight"			// 0 .. 100. Brightness of standard dots when in Night time
#define jc_BRIGHTNIGHTLEDPERCENTAGE		"brightNight"		// 0 .. 100. Brightness of Tick dots when in Night time
#define jc_TEMPERATUREPERCENTAGE		"temp"				// 0 .. 100. Brightness of temperature dot when sleeping
#define jc_LEDHUEPERCENTAGE				"hue"				// 0 .. 100. Universal color shift to apply 
#define jc_LEDCOLDHUEPERCENTAGE			"coldHue"			// 0 .. 100. Color of temperature dot when temperature < 60°
#define jc_LEDWARMHUEPERCENTAGE			"warmHue"			// 0 .. 100. Color of temperature dot when temperature > 60°
#define jc_NIGHTHOUR					"nightHour"			// 0 .. 23. Hour to start Night time
#define jc_DAYHOUR						"dayHour"			// 0 .. 23. Hour to end Night time
#define jc_OWKEY						"owAppKey"			// <string>. OpenWeather API Key
#define jc_OWLAT						"latitude"			// <float>. Location Latitude
#define jc_OWLON						"longitude"			// <float>. Location Longitude
#define jc_DSLEEP						"displaySleep"		// <int>. Sleep the display for this many seconds.
#define jc_REBOOT						"reboot"			// <>. Reboot

#define st_DSLEEPREMAINING				"sleepRemaining"	// <int>. Remaining sleep time in seconds.
#define st_TIMEZONE						"timezone"			// <int>. Timezone from OW
#define st_NEXTNTPUPDATE				"nextNTPUpdate"		// <int>. Number of seconds until the next NTP update
#define st_NEXTOWUPDATE					"nextOWUpdate"		// <int>. Number of seconds until the next OpenWeather update
#define st_TEMPERATURE					"temperature"		// <int>. Current temperature in °F
#define st_LASTOWRESPONSE				"lastOWResponse"	// <int>. Last HTTP response from OpenWeather
#define st_TIME							"time"				// <string>. Current time
#define st_DISPLAY						"display"			// <string>. Display state [Day|Night|Sleep|Preparing]
#define st_VERSION						"version"			// <string>. Clock firmware version

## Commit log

2025-11-05 Added LED Ring KiCAD Document
    [Outline.dxf, RGB Clock.kicad_pcb, RGB Clock.kicad_sch]
2025-11-05 Added Clock Controller KiCAD Document
    [RGB Clock Controller.kicad_pcb, RGB Clock Controller.kicad_sch]
2025-11-05 Added Fabrication files
    [RGB Clock Controller-B_Cu.gbr, RGB Clock Controller-B_Mask.gbr, RGB Clock Controller-B_Paste.gbr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]
2025-11-05 Corrected polarity mistake on level-shifter. Adjusted layout slightly
    [RGB Clock Controller-B_Cu.gbr, RGB Clock Controller-B_Mask.gbr, RGB Clock Controller-B_Paste.gbr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]

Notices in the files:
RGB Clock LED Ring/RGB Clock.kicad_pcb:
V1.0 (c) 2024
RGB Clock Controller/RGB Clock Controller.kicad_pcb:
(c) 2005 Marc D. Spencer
